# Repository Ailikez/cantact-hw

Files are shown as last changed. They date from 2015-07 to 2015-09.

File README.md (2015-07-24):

# CANtact Hardware

Add isolated version in [CAN Isolated](https://github.com/x893/cantact-hw/tree/master/CAN Isolated) folder.

This repository contains the hardware design files for the CANtact tool. They 
can be opened and edited with [KiCad](http://www.kicad-pcb.org/).

A PDF of the schematic is available
[here](https://github.com/CANtact/cantact-hw/blob/master/cantact.pdf?raw=true).

## License

Hardware files released under the [Creative Commons Attribution-ShareAlike 4.0
International License](http://creativecommons.org/licenses/by-sa/4.0/) (CC BY-SA
4.0)

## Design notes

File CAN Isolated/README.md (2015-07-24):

# CANtact Hardware with isolated CAN

This repository contains the hardware design files for the isolated CANtact tool.
They can be opened and edited with [CADSoft Eagle](http://www.cadsoft.de/).

A PDF of the schematics is available
[CAN1](https://github.com/x893/cantact-hw/blob/master/CAN Isolated/CAN1.pdf?raw=true)
and
[CAN2](https://github.com/x893/cantact-hw/blob/master/CAN Isolated/CAN2.pdf?raw=true)

## License

Hardware files released under the [Creative Commons Attribution-ShareAlike 4.0
International License](http://creativecommons.org/licenses/by-sa/4.0/) (CC BY-SA
4.0)

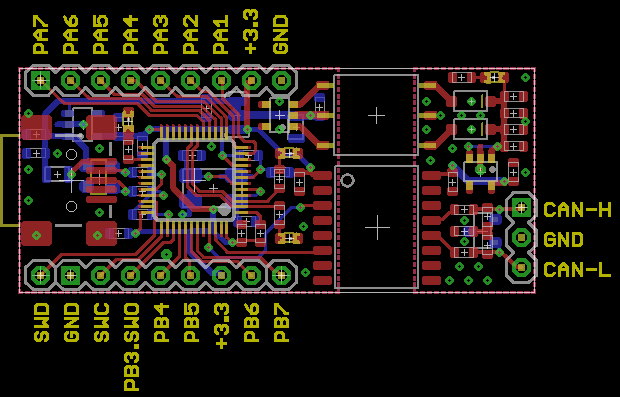
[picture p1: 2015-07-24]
CAN Isolated/CAN1.png

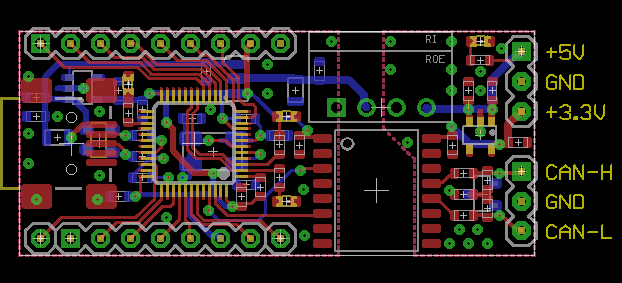
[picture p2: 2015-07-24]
CAN Isolated/CAN2.png

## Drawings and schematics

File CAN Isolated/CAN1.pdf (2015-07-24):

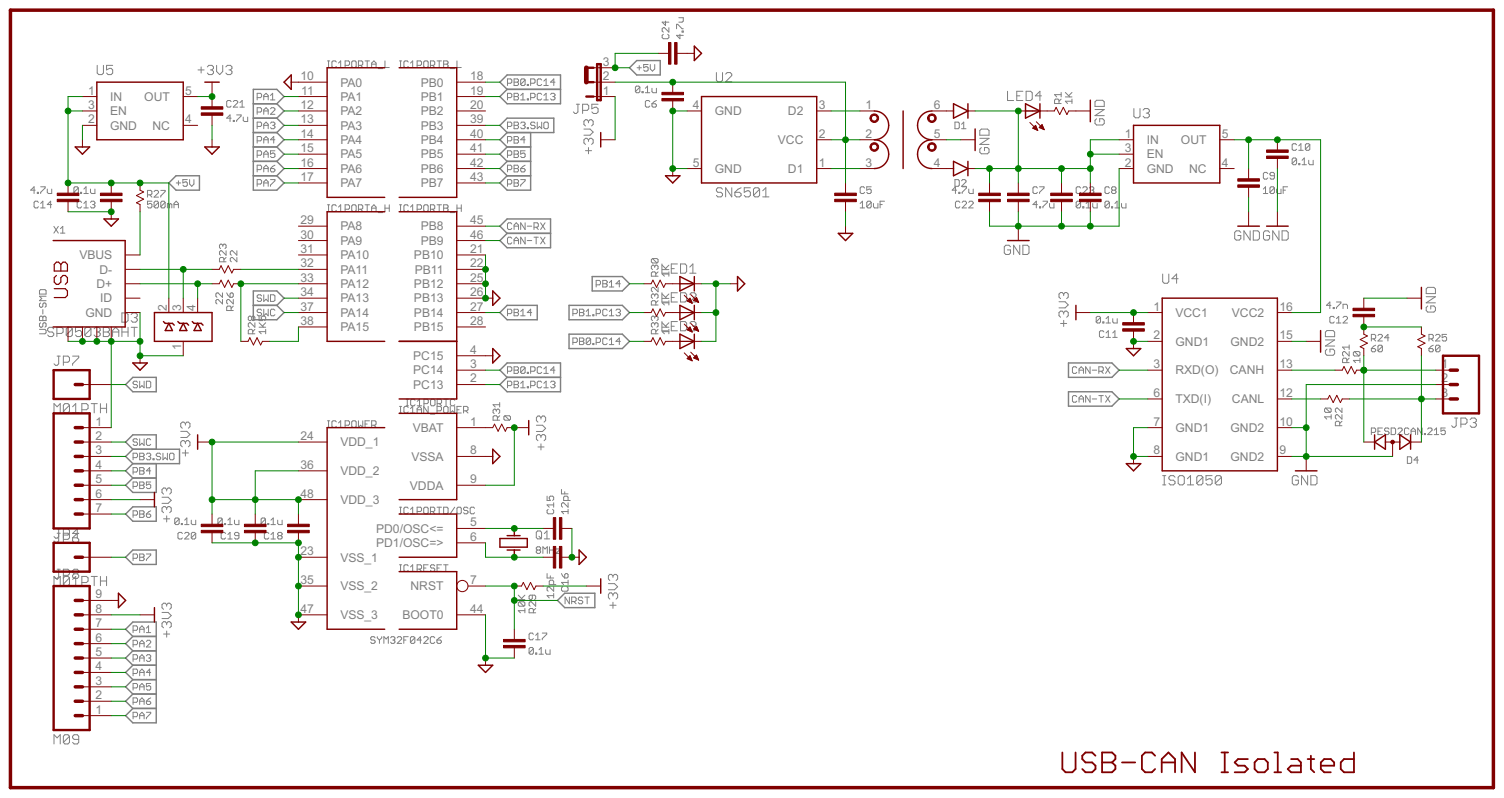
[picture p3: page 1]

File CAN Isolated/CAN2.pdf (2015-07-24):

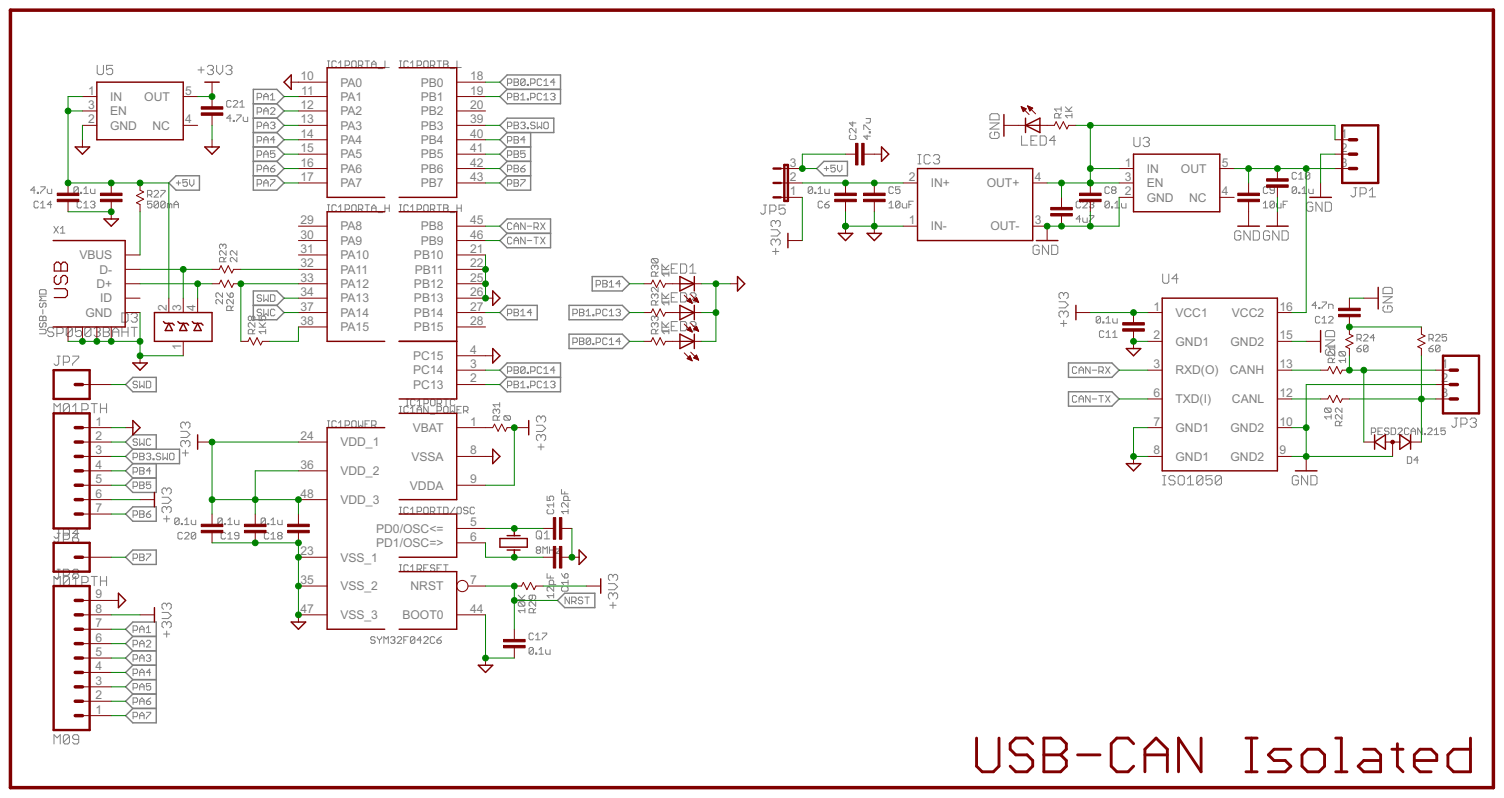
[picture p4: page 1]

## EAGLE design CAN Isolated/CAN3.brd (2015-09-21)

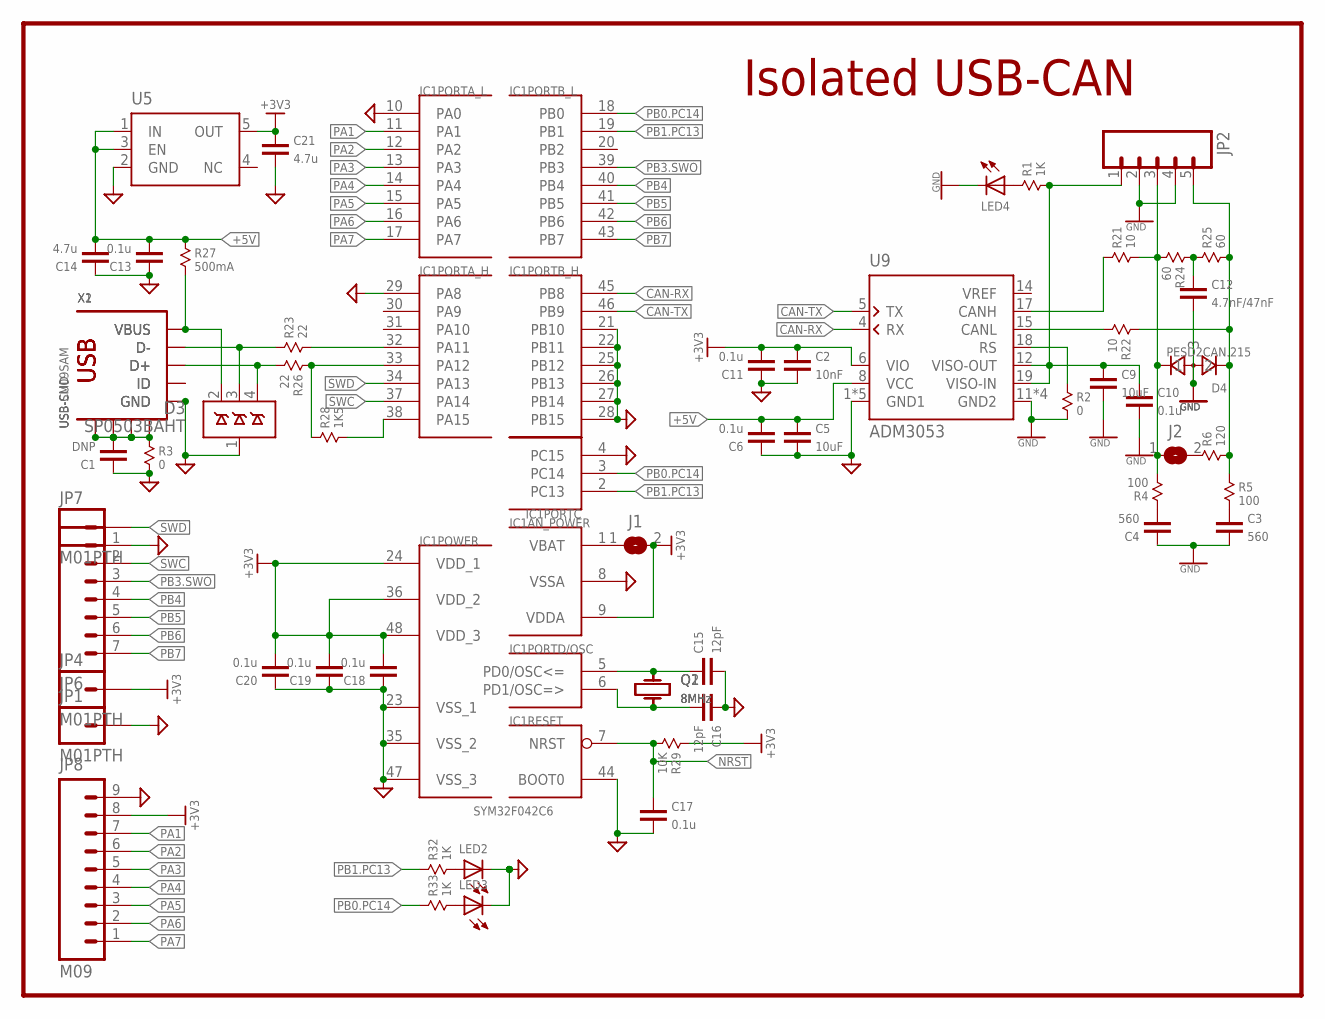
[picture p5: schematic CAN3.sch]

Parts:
C1: DNP; 0603
C2: 10nF; 0603
C3, C4: 560; 0603
C5, C9: 10uF; 0805
C6, C10, C11, C13, C17, C18, C19, C20: 0.1u; 0603
C12: 4.7nF/47nF; 0603
C14, C21: 4.7u; 0603
C15, C16: 12pF; 0603
D3: SP0503BAHT; SOT143
D4: PESD2CAN.215; SOT-23
IC1: SYM32F042C6; TQFP48
J1, J2: JUMPER2-0402
JP1, JP4, JP7: M01PTH; 1X01
JP2: M05PTH; 1X05
JP6: M07; 1X07
JP8: M09; 1X09
LED2, LED3, LED4: LEDCHIPLED_0603; CHIPLED_0603
Q1: 8MHz; KX-9A
Q2: 8MHz; KX-7
R1, R32, R33: 1K; 0603
R2, R3: 0; 0603
R4, R5: 100; 0603
R6: 120; 0603
R21, R22: 10; 0603
R23, R26: 22; 0603
R24, R25: 60; 0603
R27: 500mA; 0805
R28: 1K5; 0603
R29: 10K; 0603
U5: TPS73033; SOT23-5
U9: ADM3053; SO20W
X1: USB-SMD; USB-MINIB
X2: USB-CU09SAM; CU09SAM

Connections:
+3V3: C2.2, C11.1, C18.1, C19.1, C20.1, C21.2, IC1.9 (VDDA), IC1.24 (VDD_1), IC1.36 (VDD_2), IC1.48 (VDD_3), J1.2, JP4.1, JP8.8, R29.1, U5.5 (OUT), U9.6 (VIO)
+5V: C5.2, C6.1, C13.1, C14.1, R27.1, U5.1 (IN), U5.3 (EN), U9.8 (VCC)
CAN-H: D4.1, J2.1, JP2.3, R4.2, R21.2, R24.2
CAN-L: D4.2, JP2.5, R5.1, R6.2, R22.1, R25.2
CAN-RX: IC1.45 (PB8), U9.4 (RX)
CAN-TX: IC1.46 (PB9), U9.5 (TX)
CANH: R21.1, U9.17 (CANH)
CANL: R22.2, U9.15 (CANL)
GNDA: C3.1, C4.2, C9.1, C10.1, C12.1, D4.3, JP2.2, JP2.4, LED4.C, R2.2, U9.11 (GND2), U9.13 (GND2), U9.16 (GND2), U9.20 (GND2)
GNDD: C1.2, C2.1, C5.1, C6.2, C11.2, C13.2, C14.2, C15.1, C16.2, C17.1, C18.2, C19.2, C20.2, C21.1, D3.1 (GND), IC1.4 (PC15), IC1.8 (VSSA), IC1.10 (PA0), IC1.21 (PB10), IC1.22 (PB11), IC1.23 (VSS_1), IC1.25 (PB12), IC1.26 (PB13), IC1.27 (PB14), IC1.28 (PB15), IC1.29 (PA8), IC1.35 (VSS_2), IC1.44 (BOOT0), IC1.47 (VSS_3), JP1.1, JP6.1, JP8.9, LED2.C, LED3.C, R3.2, U5.2 (GND), U9.1 (GND1), U9.3 (GND1), U9.7 (GND1), U9.9 (GND1), U9.10 (GND1), X1.GND, X2.5 (GND)
unnamed: LED4.A, R1.1
unnamed: R2.1, U9.18 (RS)
unnamed: C12.2, R24.1, R25.1
unnamed: X1.ID, X2.4 (ID)
unnamed: C1.1, R3.1, X1.GND@1 (GND), X1.GND@2 (GND), X1.GND@3 (GND), X1.GND@4 (GND), X2.GND@1 (GND), X2.GND@2 (GND), X2.GND@3 (GND), X2.GND@4 (GND)
unnamed: IC1.1 (VBAT), J1.1
unnamed: IC1.32 (PA11), R23.2
unnamed: LED2.A, R32.2
unnamed: C3.2, R5.2
unnamed: C4.1, R4.1
unnamed: J2.2, R6.1
unnamed: LED3.A, R33.2
unnamed: IC1.33 (PA12), R26.1, R28.1
unnamed: D3.4 (D3), R26.2, X1.D+, X2.3 (D+)
unnamed: D3.3 (D2), R23.1, X1.D-, X2.2 (D-)
unnamed: D3.2 (D1), R27.2, X1.VBUS, X2.1 (VBUS)
unnamed: IC1.38 (PA15), R28.2
unnamed: C15.2, IC1.5 (PD0/OSC<=), Q1.1, Q2.1
unnamed: C16.1, IC1.6 (PD1/OSC=>), Q1.3 (2), Q2.3 (2)
NRST: C17.2, IC1.7 (NRST), R29.2
PA1: IC1.11 (PA1), JP8.7
PA2: IC1.12 (PA2), JP8.6
PA3: IC1.13 (PA3), JP8.5
PA4: IC1.14 (PA4), JP8.4
PA5: IC1.15 (PA5), JP8.3
PA6: IC1.16 (PA6), JP8.2
PA7: IC1.17 (PA7), JP8.1
PB0.PC14: IC1.3 (PC14), IC1.18 (PB0), R33.1
PB1.PC13: IC1.2 (PC13), IC1.19 (PB1), R32.1
PB3.SWO: IC1.39 (PB3), JP6.3
PB4: IC1.40 (PB4), JP6.4
PB5: IC1.41 (PB5), JP6.5
PB6: IC1.42 (PB6), JP6.6
PB7: IC1.43 (PB7), JP6.7
SWC: IC1.37 (PA14), JP6.2
SWD: IC1.34 (PA13), JP7.1
VCC2: C9.2, C10.2, JP2.1, R1.2, U9.12 (VISO-OUT), U9.19 (VISO-IN)

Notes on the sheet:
Isolated USB-CAN

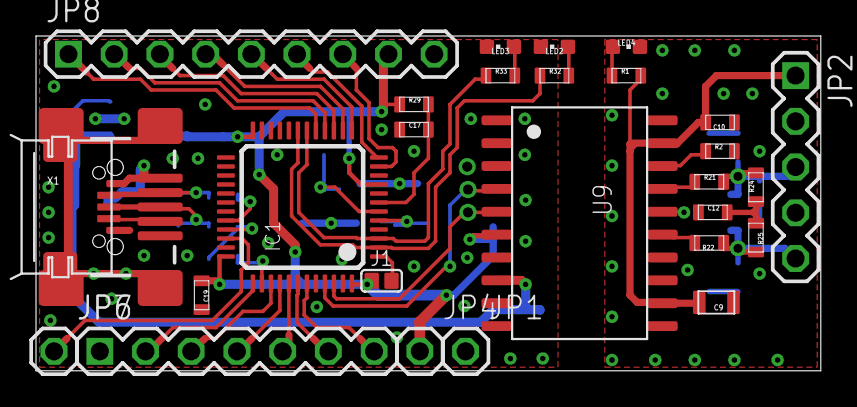
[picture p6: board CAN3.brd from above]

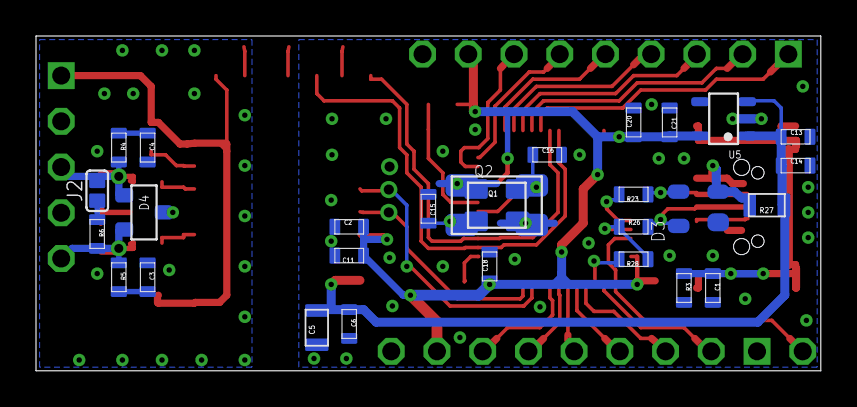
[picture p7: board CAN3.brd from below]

Board: 2 copper layers, 43.6 x 18.6 mm, 56 parts (28 on the bottom side), 47 nets.

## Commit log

2015-07-24 Add isolated CAN version with DC-DC and solid power.
    [CAN1.brd, CAN1.sch, CAN2.brd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]
2015-09-21 Add CAN3 with ADM3053
    [CAN3.brd, CAN3.sch]

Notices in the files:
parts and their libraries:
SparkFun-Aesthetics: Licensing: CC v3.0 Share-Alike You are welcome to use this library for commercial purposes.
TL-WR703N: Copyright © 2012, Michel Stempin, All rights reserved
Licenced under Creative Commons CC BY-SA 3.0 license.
